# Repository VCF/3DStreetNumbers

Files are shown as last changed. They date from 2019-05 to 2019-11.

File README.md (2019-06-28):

# 3D Printed Street Sign Numbers

I needed street numbers for both my driveway and house, 15 in
total. At big-box hardware stores these things are _pricey_. This
seemed like a perfect use of a 3D printer; Cura estimates that a 3"
high number "8" will take 17 grams of ABS and cost `$0.34`.

All characters are defined using SCAD, such that you can change the
size and/or thickness of the characters (default 3" high) and
hopefully the screw holes will be automatically relocated to the
appropriate place. You can also change the font, but you'll almost
certainly have to reposition the screw holes. The holes have a
bevel designed to fit #6 sheet metal screws.

* Default Font: Open Sans Extrabold by Steve Matteson
  * https://fonts.google.com/specimen/Open+Sans
* Designed with OpenSCAD
  * https://www.openscad.org/

Sample of characters:
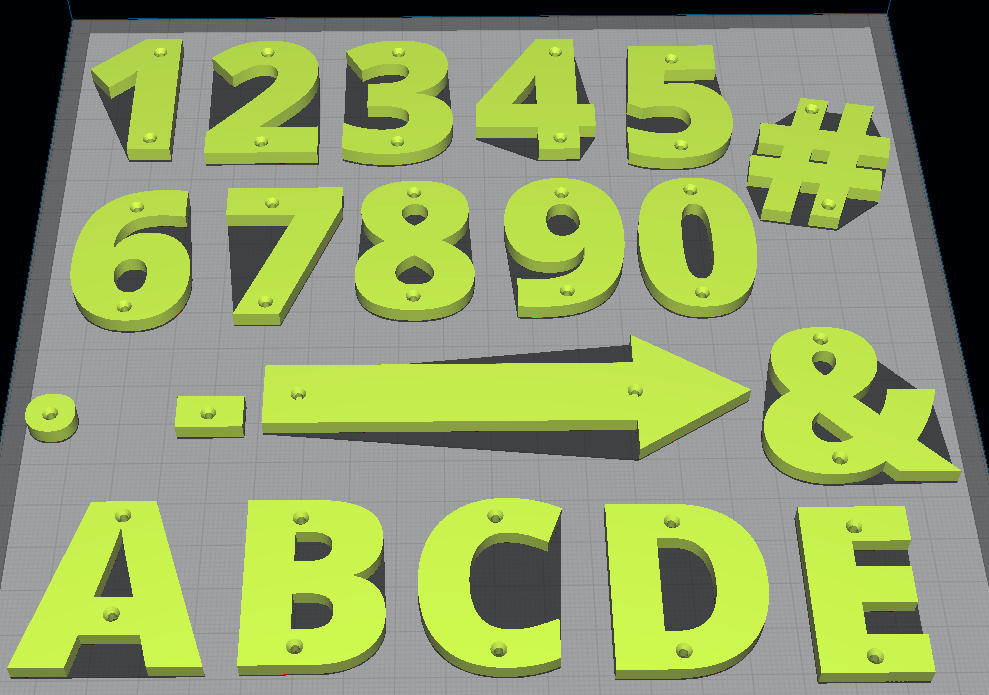
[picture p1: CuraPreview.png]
Sample in Cura


Note: [SCAD is not a programming language][NoProg]. This means if you
try someting like `scaledVal = scaledVal * scalingFactor` you'll end
up frustrated and 20 minutes poorer.

[NoProg]: http://forum.openscad.org/A-A-1-td11385.html

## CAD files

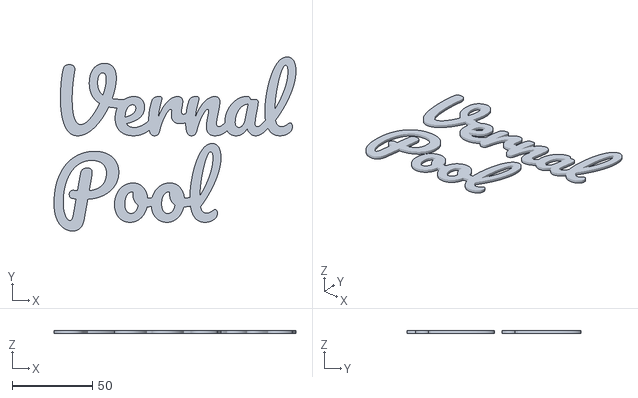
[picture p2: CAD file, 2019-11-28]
Vernal Pool.stl
151.0 x 108.6 x 2.00

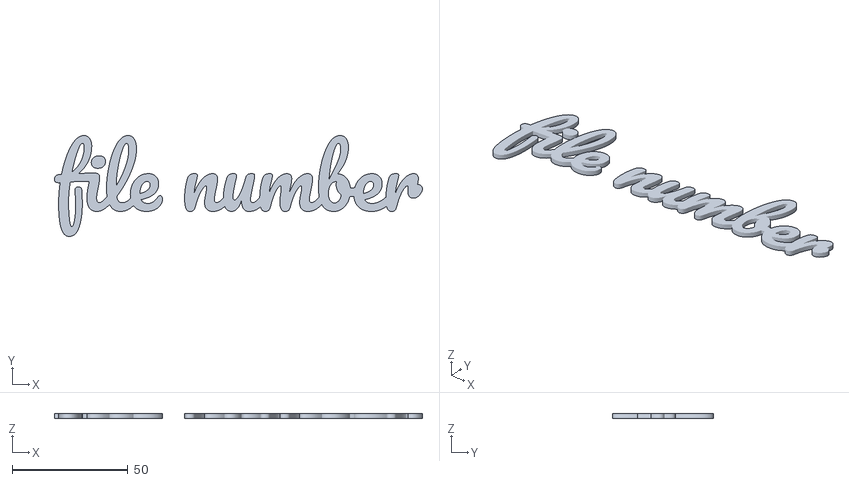
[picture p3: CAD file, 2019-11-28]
File Number.stl
159.2 x 43.6 x 2.00

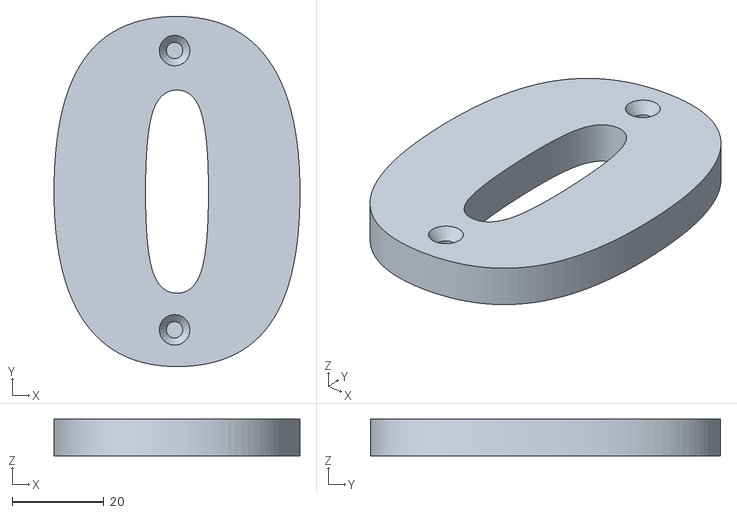
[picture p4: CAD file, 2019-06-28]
0.stl
53.7 x 76.5 x 8.00

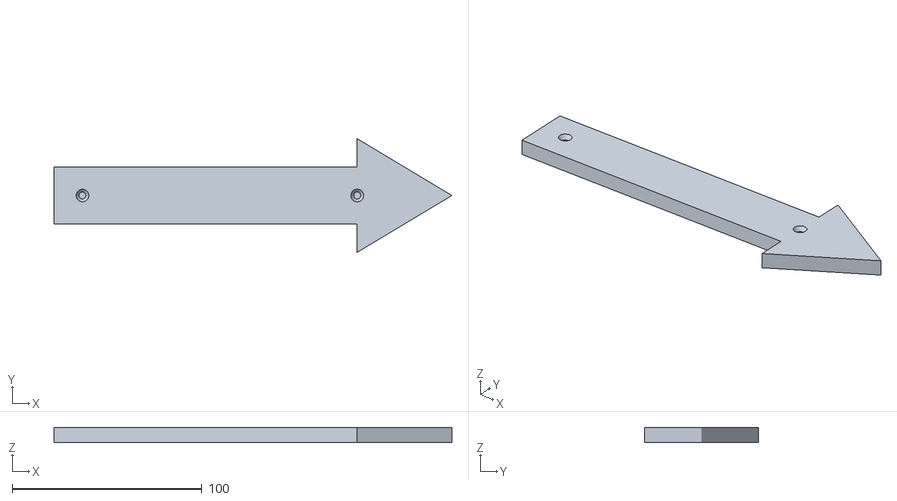
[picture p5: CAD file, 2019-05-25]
ArrowSubtle.stl
210.0 x 60.0 x 8.00

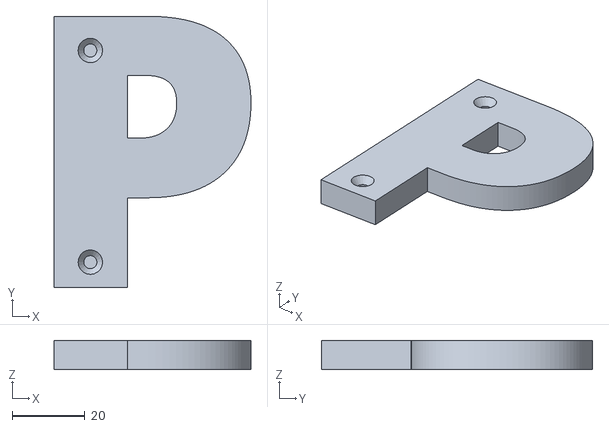
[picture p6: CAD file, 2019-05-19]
P.stl
54.0 x 74.4 x 8.00

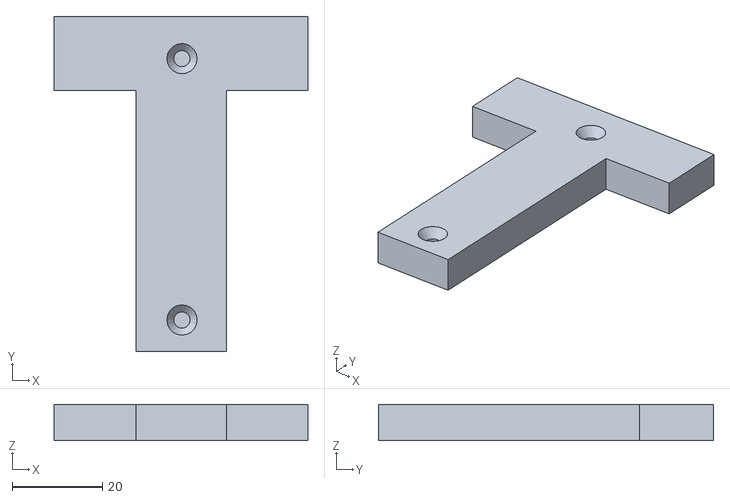
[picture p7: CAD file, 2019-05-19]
T.stl
56.4 x 74.4 x 8.00

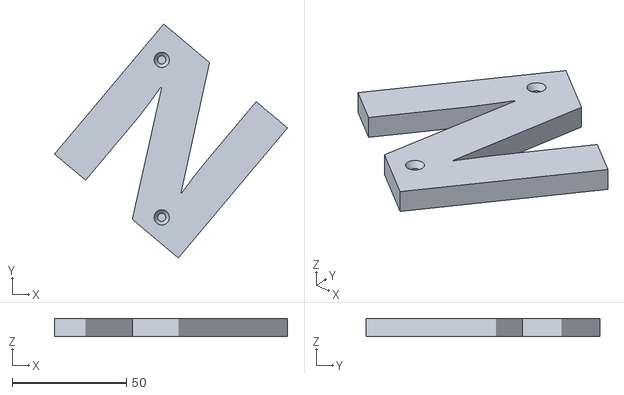
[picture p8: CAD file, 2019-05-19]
N.stl
102.1 x 102.5 x 8.00

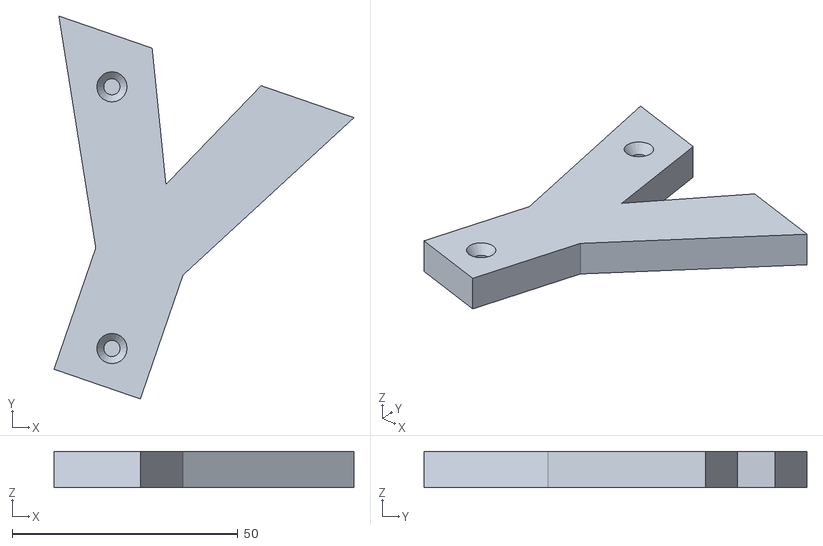
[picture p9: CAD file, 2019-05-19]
Y.stl
66.5 x 84.9 x 8.00

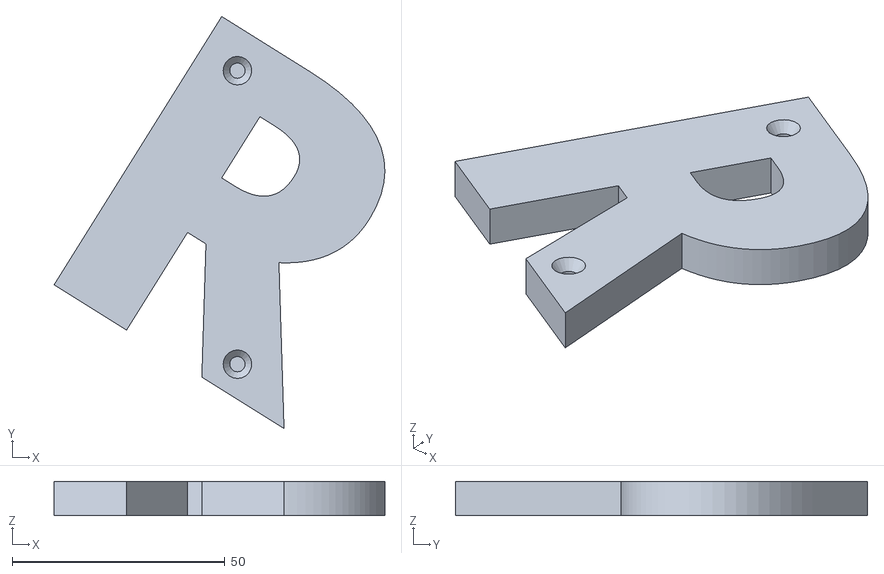
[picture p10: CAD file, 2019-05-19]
R.stl
77.8 x 96.8 x 8.00

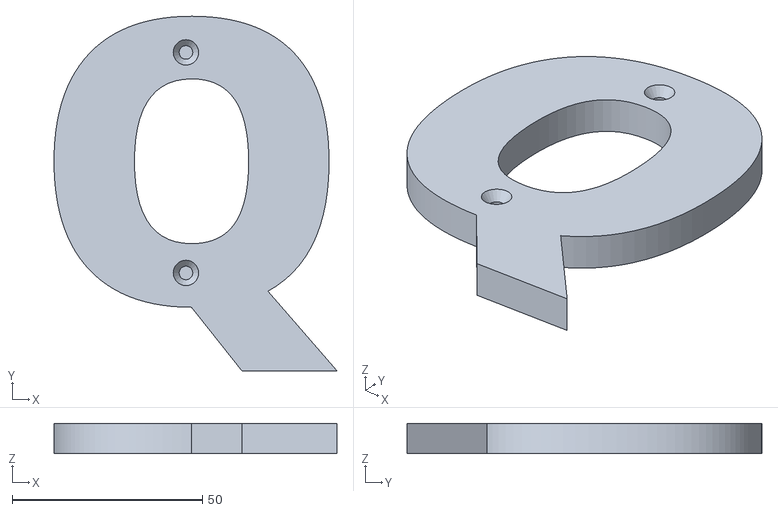
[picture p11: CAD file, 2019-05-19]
Q.stl
74.4 x 93.2 x 8.00

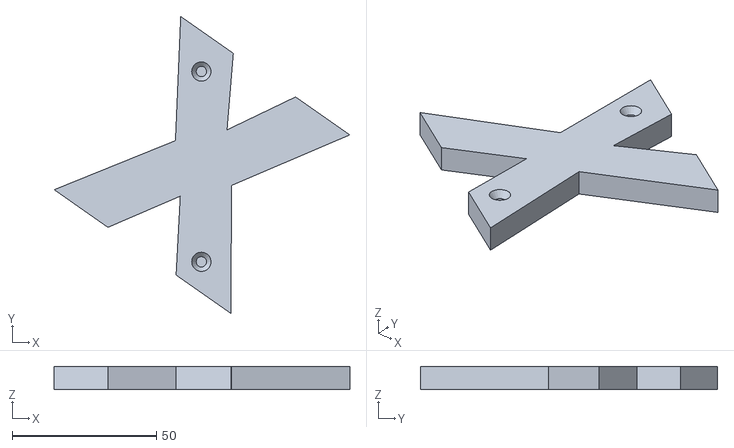
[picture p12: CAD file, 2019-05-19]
X.stl
102.5 x 103.0 x 8.00

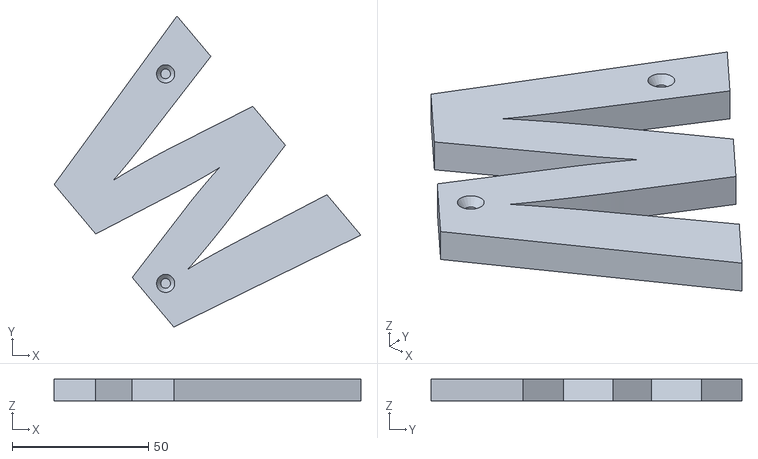
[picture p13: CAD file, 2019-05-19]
W.stl
112.7 x 114.3 x 8.00

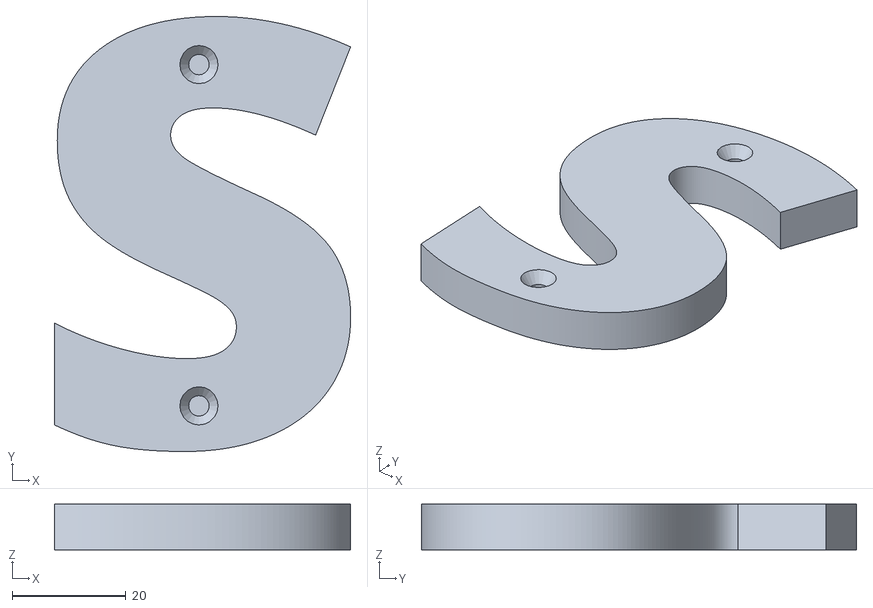
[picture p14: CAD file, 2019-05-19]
S.stl
52.1 x 76.5 x 8.00

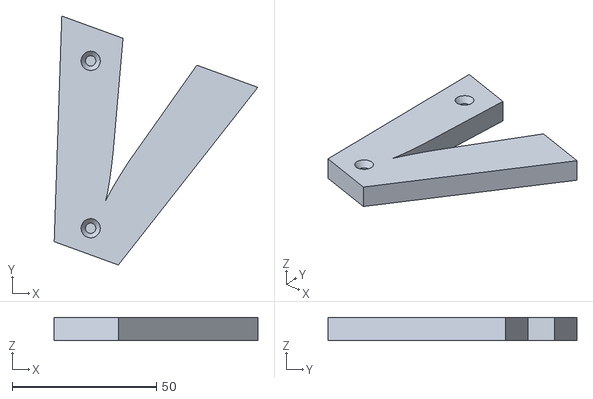
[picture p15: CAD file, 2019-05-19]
V.stl
70.6 x 86.3 x 8.00

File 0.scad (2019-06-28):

// Street Numbers for 3D printing
// Charles Tilford, 2019
// License: CC BY-NC-SA 4.0
//   https://creativecommons.org/licenses/by-nc-sa/4.0/

char="0";     // The number/letter to print

// Units are in mm, except for height of letter

// How many inches high should letter be?
inchesHigh=3;
// How thick/deep should letter be (mm)?
depth=8;

// Character coordinates just center the letter
charX=-30;    // Character X coord
charY=-35;    // Character Y coord
topScrew=33;  // Top screw Y coord
botScrew=-28; // Bottom screw Y coord
height=8;     // Thickness of character
// Screw dimensions. Default presumes
// #6 sheet metal screw
screwWid=3.6; // Width of screw shaft
screwTop=6.78;// Width of screw head
screwCon=5.08;// Height of head 'cone'

// Font to print in. Your system needs this
// installed, of course. If changed the hole
// positions almost certainly need to be
// changed, and maybe charX/charY.
fName="Open Sans Extrabold";
// https://fonts.google.com/specimen/Open+Sans
// Designer: Steve Matteson

// Thin floor below holes. My printer was
// struggling to have the hole 'border' stick
// to the stage. Just drill/screw thru it.
holeFloor=0.15; 

// ==========================================
// ===== All values below are auto-calculated
// ==========================================

// Scaled values
scaleFactor=inchesHigh / 3;
cX=charX * scaleFactor;
cY=charY * scaleFactor;
tS=topScrew * scaleFactor;
bS=botScrew * scaleFactor;
// Where do we start drawing screw head cone?
oS=depth - (screwCon-.05);

difference() {
  // We use difference() to punch out the screw holes
  // in the character
    
  // The character itself, 8mm thick
  translate([cX,cY,0])
    linear_extrude(height=depth, scale=1)
    text(char, size=(75*scaleFactor),
         $fn=100, font=fName);
    
  // Bottom screw hole
  translate([0,bS,oS]) color("red")
    cylinder(h=screwCon, d2=screwTop,
             d1=0, $fn=20);
   translate([0,bS,holeFloor])
    cylinder(h=20, d=screwWid, $fn=20);
    
  // Top screw hole
  translate([0,tS,oS]) color("red")
    cylinder(h=screwCon, d2=screwTop,
             d1=0, $fn=20);
  translate([0,tS,holeFloor])
    cylinder(h=20, d=screwWid, $fn=20);
}

// Colors are just to aid visualization of
// void spaces. $fn is "featuer number", ie how
// many polygons are devoted to object. The values
// above should be near your printing limit anyway.

// Developed in OpenSCAD
//    https://www.openscad.org/

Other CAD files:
Z.stl
O.stl
U.stl
num.stl
1.scad
2.scad
3.scad
1.stl
2.stl
3.stl
4.scad
4.stl
5.scad
5.stl
6.scad
6.stl
7.scad
7.stl
8.scad
8.stl
9.scad
9.stl
A.scad
A.stl
ArrowSubtle.scad
B.scad
B.stl
C.scad
C.stl
D.scad
D.stl
E.scad
E.stl
F.scad
F.stl
FOOBAR.scad
File Number.scad
G.scad
G.stl
H.scad
H.stl
I.scad
I.stl
J.scad
J.stl
K.scad
K.stl
L.scad
L.stl
M.scad
M.stl
N.scad
O.scad
P.scad
Q.scad
R.scad
S.scad
T.scad
U.scad
V.scad
Vernal Pool.scad
W.scad
X.scad
Y.scad
Z.scad
and.scad
and.stl
dash.scad
dash.stl
dot.scad
dot.stl
num.scad

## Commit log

2019-05-18 Template used for spamming out all the individual letters/numbers/etc
    [FOOBAR.scad]
2019-05-18 Numbers 0-9
    [0.scad, 0.stl, 1.scad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]
2019-05-18 Letters A-M
    [A.scad, A.stl, B.scad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]
2019-05-19 Letters N-Z
    [N.scad, N.stl, O.scad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]
2019-05-25 Simple arrow
    [ArrowSubtle.scad, ArrowSubtle.stl]
2019-05-27 Sample of characters
2019-05-27 note screw size
2019-06-28 hole floor didn't render for some reason
    [0.scad, 0.stl]
2019-11-28 NOI signs
    [File Number.scad, File Number.stl, Vernal Pool.scad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]
